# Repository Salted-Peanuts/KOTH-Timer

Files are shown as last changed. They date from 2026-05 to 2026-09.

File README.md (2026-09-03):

# KOTH-Timer

A DIY Arduino Nano ESP32 King of the Hill timer for Nerf, foam flinging, skirmish games, and objective-based events.

KOTH-Timer is an open-source physical game timer with arcade buttons, TM1637 displays, battery monitoring, and a local phone-friendly referee/admin web interface. It is designed for two-team King of the Hill games where players physically hold a button to capture the objective.

This project is based on a working timer that has been tested successfully at local Nerf events. A few people in the hobby scene asked how to build their own, so this repo exists to make that possible.

The goal is to keep it practical, buildable, and easy to modify.

## Current Recommended Versions

The current recommended firmware release is:

```text
v0.3.1
```

v0.3.1 is the recommended firmware for new builds.

It keeps the tested v0.3 phone/referee UI and adds small UI input fixes so team colours and match duration can be edited more reliably from the web interface.

Recommended PCB revision:

```text
v0.2
```

PCB v0.2 has been manufactured, assembled, and tested with no known faults. It is the recommended PCB revision for new builds.

The tested KOTH Timer PCB v0.2 project is available on PCBWay for convenience if you choose to use them:

[Order / view the KOTH Timer PCB v0.2 project on PCBWay](https://www.pcbway.com/project/shareproject/King_Of_The_Hill_ESP32_based_timer_1aeedfa7.html)

Older versions remain available for reference but are not recommended for new builds:

| Version | Status |
| --- | --- |
| Firmware v0.3 | Event-tested release, replaced by v0.3.1 bug-fix update |
| PCB v0.1 | Manufactured, functional through the web UI, but has known display issues |

## What It Does

KOTH-Timer is a physical objective timer for two-team King of the Hill style games.

Players press their team’s button to capture the objective. The timer tracks control time and shows the game state through:

* Large physical displays
* Button LED feedback
* A local referee/admin web interface

The timer runs locally from the ESP32, so it does not need internet access during gameplay.

## Prototype Photos

### Finished Prototype

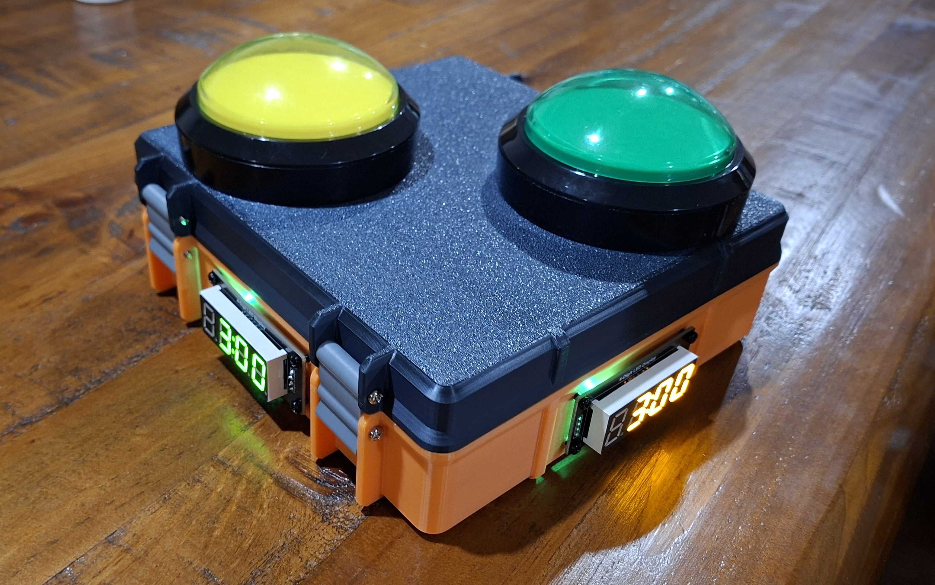
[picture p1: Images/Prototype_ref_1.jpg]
KOTH-Timer Timer finished prototype


### Inside Wiring

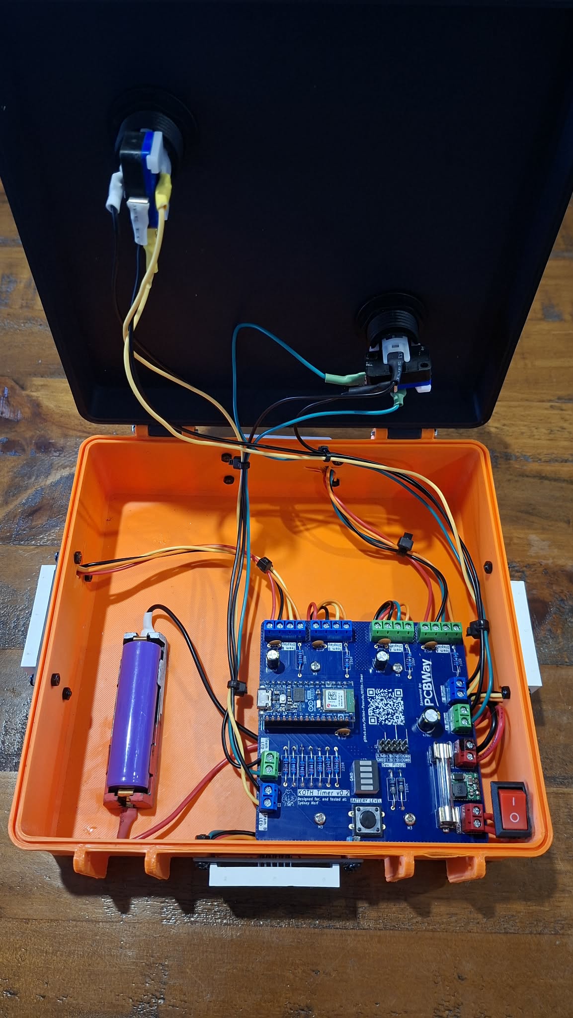
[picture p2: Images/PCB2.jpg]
KOTH-Timer Timer internal wiring


### Custom PCB

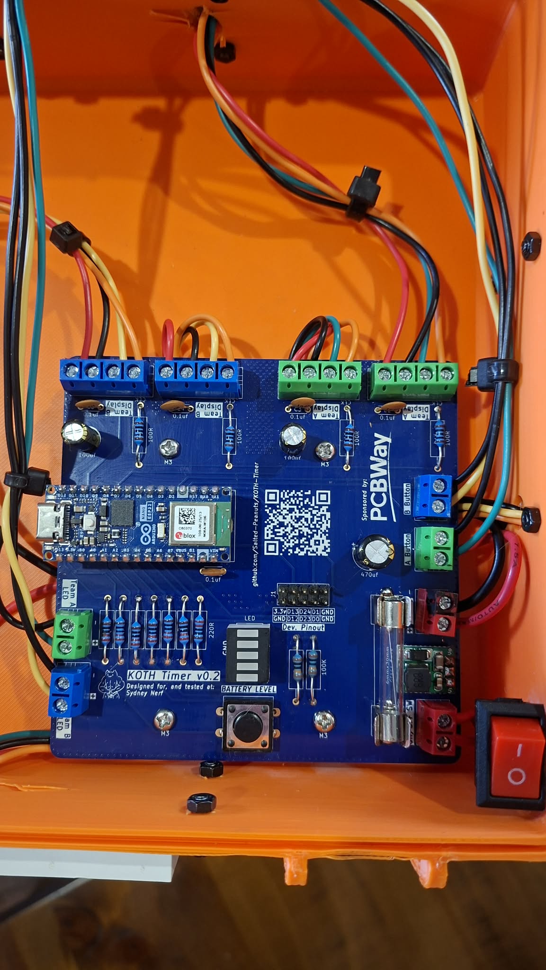
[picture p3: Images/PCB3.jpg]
KOTH-Timer Timer custom PCB


## Features

* Two-team King of the Hill timer
* Physical arcade button controls
* LED button feedback
* Four TM1637 4-digit display modules
* Local ESP32-hosted web interface
* Phone-friendly referee/admin controls
* Configurable match duration
* Configurable team colours
* Battery voltage display
* Pause and resume controls
* Reset lockout to prevent accidental resets
* Game-over winner display
* Live referee time adjustment during gameplay
* Open Wi-Fi network by default for quick event setup
* Optional Wi-Fi password support
* No internet required during gameplay

## Referee/Admin Connection

The timer creates its own local Wi-Fi network.

```text
SSID: KOTH-Timer
Password: none / open network
```

After connecting, open:

```text
http://10.10.10.1
```

Connection test page:

```text
http://10.10.10.1/ping
```

Some phones may warn that the network has no internet. This is normal. Choose the option to stay connected or use the network anyway.

## Optional Wi-Fi Password

The Wi-Fi network is open by default so referees can connect quickly during events.

If you want to add a password, edit the firmware near the top of the code.

Find:

```cpp
static const char* AP_PASS = "";
```

Change it to a password with at least 8 characters:

```cpp
static const char* AP_PASS = "kothtimer";
```

Then upload the firmware again.

## Who This Is For

This project is for hobbyists who want to build their own objective timer for games such as:

* Nerf events
* Foam flinging games
* Gel blaster games where legal
* Airsoft-style objective games where legal
* Backyard or club-based capture games
* Custom scenario games

You do not need to be an expert programmer, but you should be comfortable with basic wiring, soldering, and flashing an ESP32.

## Basic Hardware Needed

The current build uses:

* Arduino Nano ESP32
* 18650 Li-ion cell
* 18650 battery holder
* 5 V boost converter
* Fuse
* Rocker power switch
* 2 large arcade buttons with LEDs
* 4 TM1637 4-digit display modules
* 5-segment battery indicator
* Battery display button
* Resistors
* Wire
* Enclosure
* USB cable for flashing
* Basic soldering tools

See the `docs` folder for the BOM, schematic, and full build guide.

## Build Guide

Start here:

[Build Guide](docs/build-guide.md)

The build guide covers:

* Parts required
* Tools required
* Power wiring
* Arduino Nano ESP32 pinout
* Button wiring
* Display wiring
* Battery indicator wiring
* Firmware upload
* Wi-Fi connection
* Event-day testing
* Troubleshooting

## Firmware

The firmware is written for the Arduino Nano ESP32 using the Arduino IDE.

Current recommended firmware:

```text
Firmware/KOTH_Timer_v0_3_1/KOTH_Timer_v0_3_1.ino
```

For Arduino IDE compatibility, the `.ino` file should be inside a folder with the same name as the sketch.

## Hardware Files

Hardware documentation is in the `docs` folder.

Current files include:

```text
docs/BOM.xlsx
docs/BOM.csv
docs/Wiring_schematic.pdf
docs/build-guide.md
```
## PCB Hardware Status

The KOTH Timer now has a tested PCB revision.

| PCB revision | Status | Recommendation |
|---|---|---|
| `v0.1` | Manufactured and functionally usable through the web UI, but has known TM1637 display reliability issues | Reference only / not recommended for new builds |
| `v0.2` | Manufactured, assembled, and tested with no known faults | Recommended PCB revision |

### PCB v0.1

PCB v0.1 was the first manufactured PCB revision.

It is functional through the web UI, but some TM1637 displays may show interference, flicker, incorrect segments, or unstable output.

The v0.1 files are kept in the repo for reference, troubleshooting, and comparison, but new builders should use PCB v0.2 instead.

### PCB v0.2

PCB v0.2 is the current recommended PCB revision.

It was redesigned based on lessons from v0.1, with improvements around display reliability, local display decoupling, and cleaner TM1637 signal routing.

PCB v0.2 has been manufactured, assembled, and tested with no known faults.

## Supported By PCBWay

PCB manufacturing for newer KOTH Timer PCB revisions has been supported by **PCBWay**.

PCBWay helped support this open-source hardware project by providing PCB manufacturing support while allowing the firmware, design files, known issues, and documentation to remain open source.

Their support made it easier to test real PCB revisions, improve the board design, and share the results back with other builders.

You can check out PCBWay’s PCB manufacturing and assembly services here:

[PCBWay](https://pcbway.com/g/EGJ27l)

The tested KOTH Timer PCB v0.2 project is available on PCBWay here:

[Order / view the KOTH Timer PCB v0.2 project on PCBWay](https://www.pcbway.com/project/shareproject/King_Of_The_Hill_ESP32_based_timer_1aeedfa7.html)

Thanks to PCBWay for supporting open-source hardware creators and helping this project move from a hand-wired prototype to a tested PCB-based build.

Note: PCBWay supported manufacturing for this project, but the design notes, testing results, known issues, and recommendations in this repository are written independently.

## Future Development

Planned future work may include:

* Improving hardware documentation
* Adding more photos and wiring diagrams
* Adding extra game modes beyond King of the Hill
* Improving the referee/admin interface based on event feedback
* Exploring a Bluetooth or app-based version if there is enough interest

The v0.3.1 firmware is the current recommended release. It is based on the event-tested v0.3 firmware and includes additional web-interface input fixes.

PCB v0.2 has been manufactured, assembled, and tested with no known faults and is the current recommended PCB revision.

## Project Status

This is a hobby project, not a commercial product.

The current firmware has been tested at an event, but builders should still test their own wiring and setup before using the timer in a game.

If you build one, feel free to modify it for your own event rules, enclosure, buttons, battery setup, or game style.

## Related Uses

This project may be useful for:

- Nerf King of the Hill games
- Foam flinging objective games
- DIY skirmish game timers
- Arduino ESP32 game props
- Capture point timers
- Referee-controlled event timers
- Local Wi-Fi game control panels

## Licence

This project is released under the MIT Licence.

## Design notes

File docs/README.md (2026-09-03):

## KOTH Timer Documentation

This folder contains the main hardware and build documentation for the KOTH Timer.

The current recommended firmware release is **v0.3.1**.

v0.3.1 has been tested and is now the recommended version for new builds.

## PCBWay Project Link

This tested PCB revision is available as a PCBWay shared project:

[Order / view the KOTH Timer PCB v0.2 project on PCBWay](https://www.pcbway.com/project/shareproject/King_Of_The_Hill_ESP32_based_timer_1aeedfa7.html)

This link is useful for builders who want to order the tested PCB without manually uploading the Gerber files.

## Build Guide

Start here:

```text
docs/build-guide.md
```

The build guide covers:

* Required parts
* Required tools
* Wiring overview
* Arduino Nano ESP32 pinout
* Power wiring
* Button wiring
* Display wiring
* Battery indicator wiring
* Firmware upload
* Wi-Fi/admin page connection
* Event testing
* Troubleshooting

## BOM

The bill of materials is available in two formats:

```text
docs/BOM.xlsx
docs/BOM.csv
```

Use the Excel file if you want the formatted version.

Use the CSV file if you want something easier to view directly on GitHub.

## Schematic

The current wiring schematic is available as a PDF:

```text
docs/Wiring_schematic.pdf
```

Use the schematic together with the build guide and firmware pinout before soldering.

## Firmware Version

The current recommended firmware is:

```text
v0.3.1
```

The older v0.2 and v0.3 firmware releases remain available for reference, but new builders should use v0.3.1:

```text
Firmware/KOTH_Timer_v0_3_1/KOTH_Timer_v0_3_1.ino
```

## Wi-Fi/Admin Interface

By default, the timer creates an open Wi-Fi network:

```text
SSID: KOTH-Timer
Password: none / open network
```

After connecting, open:

```text
http://10.10.10.1
```

Connection test page:

```text
http://10.10.10.1/ping
```

The timer does not provide internet access. This is normal.

Some phones may warn that the Wi-Fi network has no internet. Choose the option to stay connected or use the network anyway.

## Optional Wi-Fi Password

The Wi-Fi network is open by default for quick event setup.

To add a password, edit the firmware.

Find:

```cpp
static const char* AP_PASS = "";
```

Change it to a password with at least 8 characters:

```cpp
static const char* AP_PASS = "kothtimer";
```

Then upload the firmware again.

## Notes

This hardware is based on the tested prototype build.

Check all wiring carefully before powering the device.

Some parts may need different resistor values or pin assignments depending on the exact components used.

Use a multimeter before connecting the Arduino and displays to the battery power system.

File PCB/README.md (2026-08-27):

# KOTH Timer PCB Files

This folder contains PCB design files for the KOTH Timer.

Check the status of each PCB revision before ordering or manufacturing boards.

## PCB Revision Status

| Revision | Status | Use |
|---|---|---|
| `v0.1` | Manufactured, functionally usable through the web UI, known display issues | Reference only / not recommended for new builds |
| `v0.2` | Manufactured, assembled, and tested with no known faults | Recommended PCB revision |

## PCB v0.1

PCB v0.1 was the first manufactured PCB revision.

It is functionally usable through the timer’s web UI, but it has known TM1637 display reliability issues.

Known issue:

- Some TM1637 displays may show interference, flicker, incorrect segments, or unstable output.

Possible contributing factors include:

- Shared TM1637 clock routing
- Not enough local decoupling near the display headers
- Display power noise
- Signal integrity issues on CLK/DIO traces
- Long display wiring or cable effects

This revision is kept for reference and comparison, but it is not recommended for new builders.

## PCB v0.2

PCB v0.2 is the current recommended PCB revision.

It has been manufactured, assembled, and tested with no known faults.

This revision improves on v0.1, especially around:

- TM1637 display reliability
- Local display power decoupling
- Cleaner display signal routing
- Improved PCB layout
- Reduced display interference issues

## Recommendation

For new builders:

- Use the current recommended firmware.
- Use PCB v0.2 if building from a PCB.
- Use PCB v0.1 only for reference or debugging.
- Check the main build guide before ordering parts or assembling the board.

## Supported By PCBWay

PCB manufacturing for newer KOTH Timer PCB revisions has been supported by PCBWay.

Their support helped make it possible to test real PCB revisions and keep the project open source.

The tested KOTH Timer PCB v0.2 project is available on PCBWay here:

[Order / view the KOTH Timer PCB v0.2 project on PCBWay](https://www.pcbway.com/project/shareproject/King_Of_The_Hill_ESP32_based_timer_1aeedfa7.html)

Project files, known issues, testing notes, and recommendations remain documented openly so other builders can inspect, build, and improve the design.

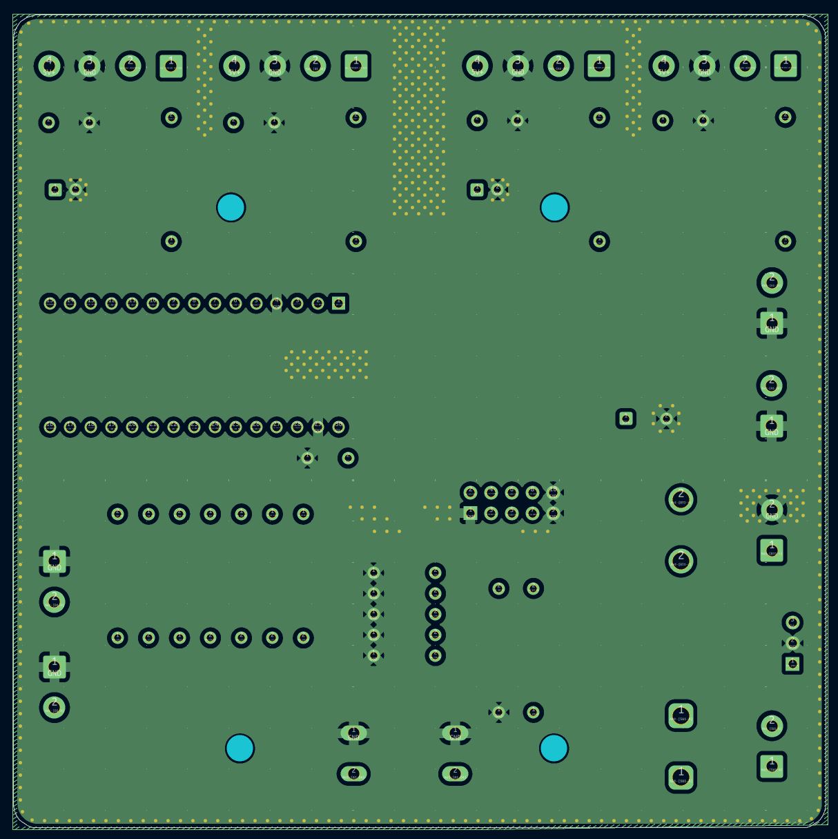
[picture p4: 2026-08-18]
Images/v0.2_Layer2.JPG

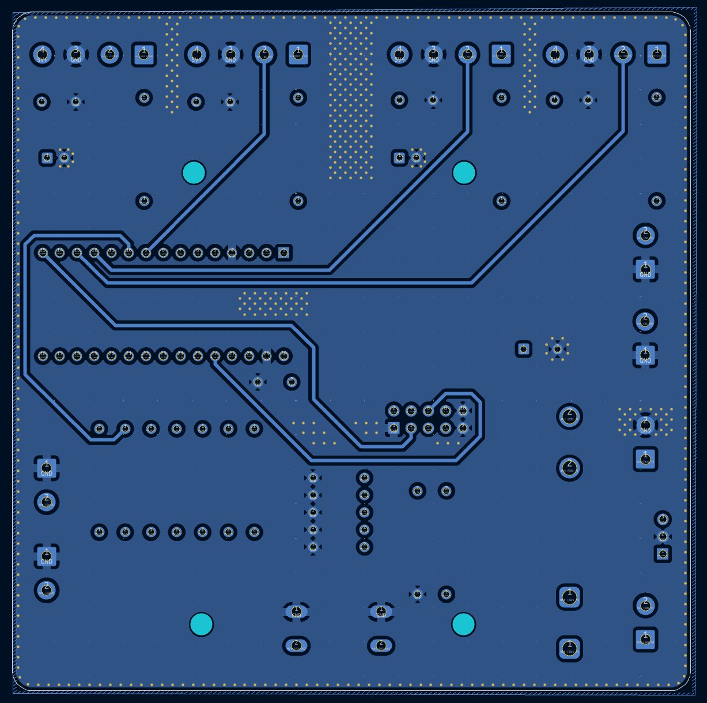
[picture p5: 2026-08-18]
Images/v0.2_Layer4.JPG

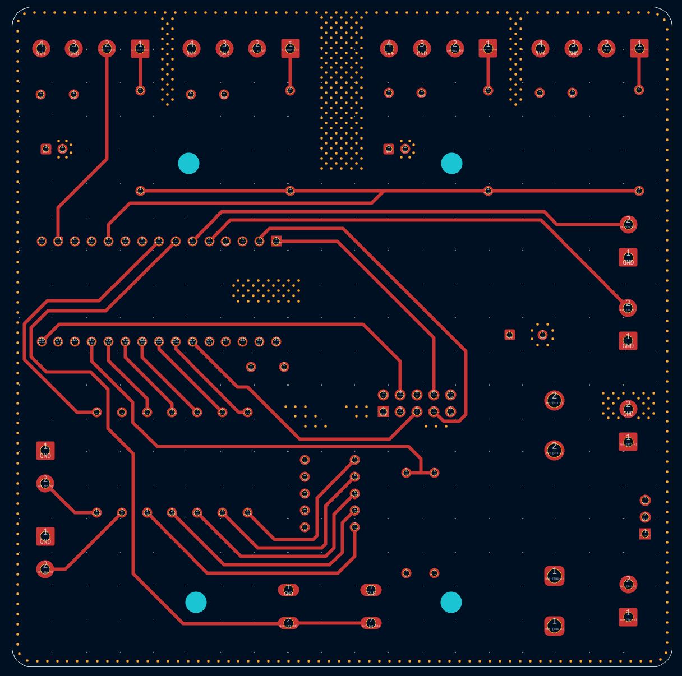
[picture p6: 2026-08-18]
Images/v0.2_Layer1.JPG

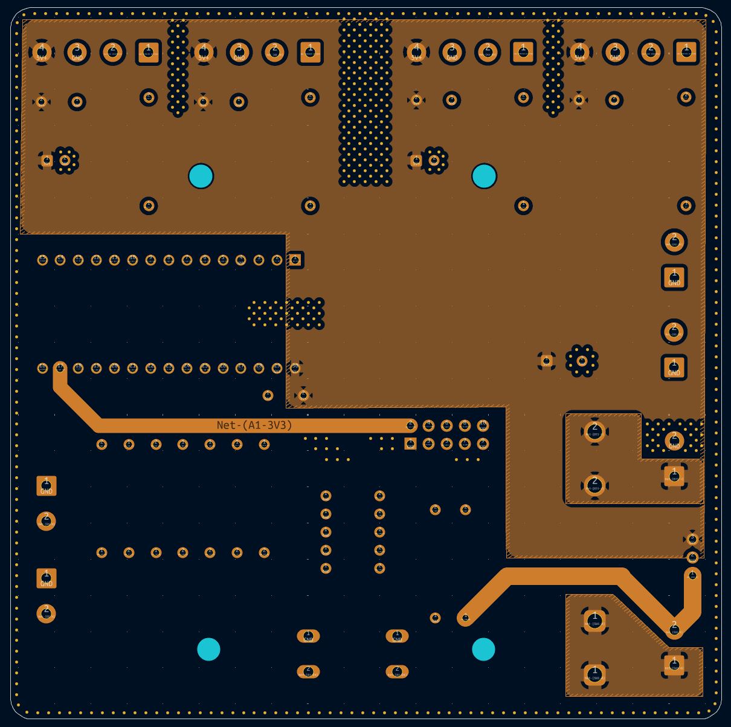
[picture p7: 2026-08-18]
Images/v0.2_Layer3.JPG

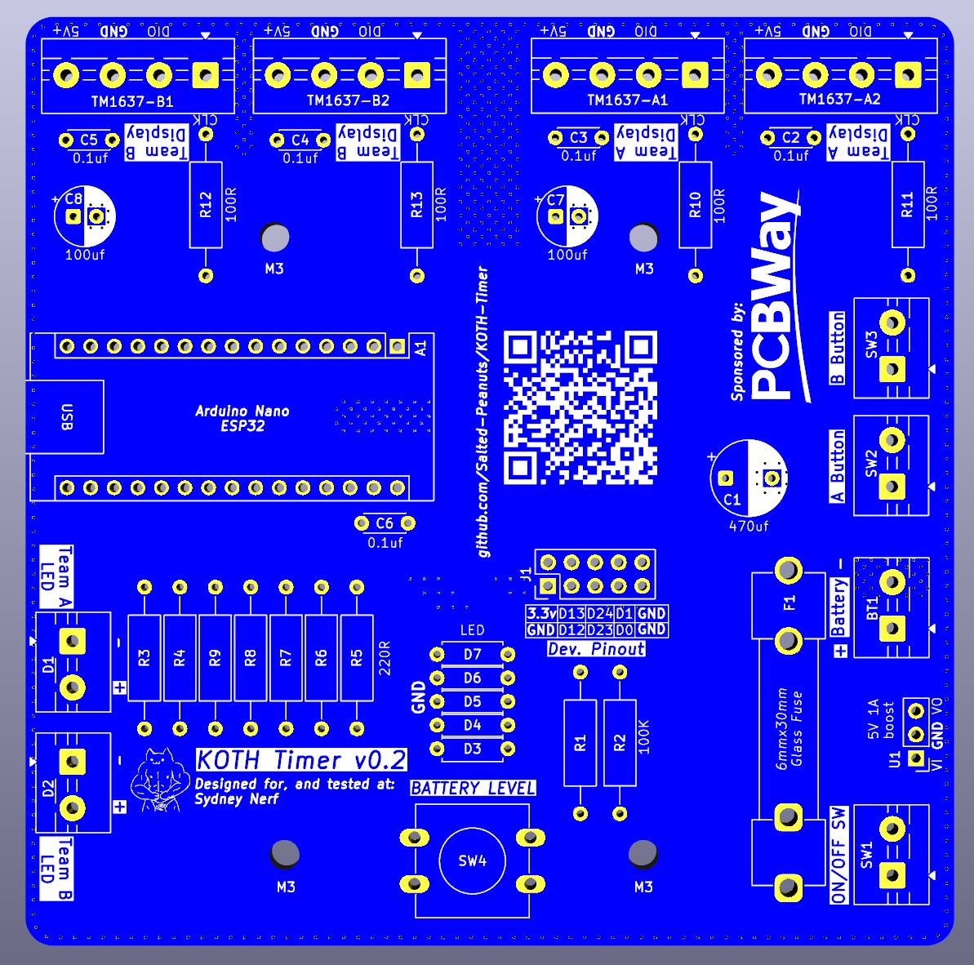
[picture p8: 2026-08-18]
Images/v0.2_FRONT.JPG

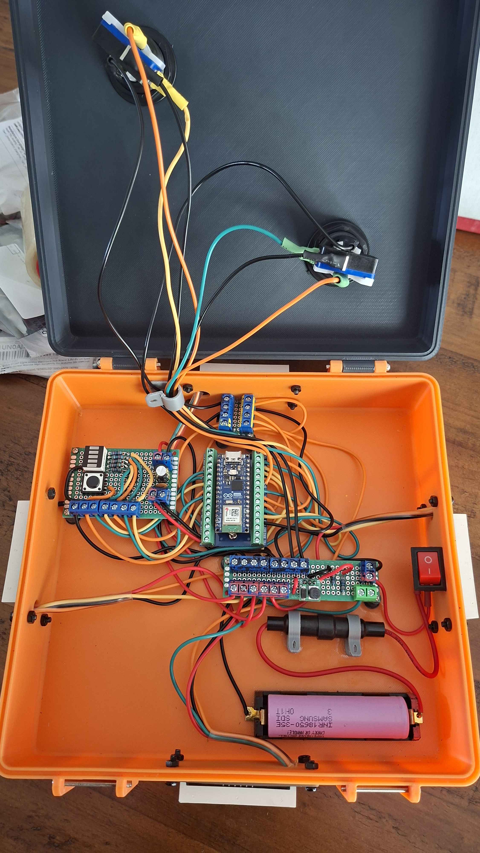
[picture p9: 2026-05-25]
Images/Prototype_ref_3.jpg

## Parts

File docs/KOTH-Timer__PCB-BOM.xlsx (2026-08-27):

 |  |  | KOTH-Timer BOM
Item # | *Designator | Qty | Manufacturer | Description / Value | Package/Footprint | Type | Your Instructions / Notes
1 | A1 | 1 | Arduino | Arduino NANO-ESP32 | Arduino Nano ESP32 module / header footprint | THT | Main controller module
2 | U1 | 1 |  | 5V step-up / boost converter module | 2.54mm pitch | THT | 1 Amp
3 | BT1, D1, D2, SW1, SW2, SW3 | 6 |  | Terminal Block - 2 pin (5mm pitch) | 2-pin 5.00mm pitch | THT
4 | TM1637-A1, TM1637-A2, TM1637-B1, TM1637-B2 | 4 |  | Terminal Block - 4 pin (5mm pitch) | 4-pin 5.00mm pitch | THT
5 | F1 | 2 |  | Fuse Clips for 6mm x 30mm Glass | 6x30mm fuse clip | THT | Pair of clips holds one fuse
6 | SW4 | 1 |  | 12mm push button switch | 12mm push button | THT
7 | D3-D7 | 1 |  | 5 Segment Bar Graph LED Display Module | 5-segment LED module | THT
8 | J1 | 1 |  | 10 pin double row (2x5) Pin header - 2.54mm pitch | 2x5 2.54mm pitch | THT
9 | R1, R2 | 2 |  | 100K resistor | Axial resistor | THT
10 | R3-R9 | 7 |  | 220R resistor | Axial resistor | THT
11 | R10-R13 | 4 |  | 100R resistor | Axial resistor | THT
12 | C1 | 1 |  | 470uF electrolytic capacitor | Radial electrolytic | THT | Observe polarity
13 | C7, C8 | 2 |  | 100uF electrolytic capacitor | Radial electrolytic | THT | Observe polarity
14 | C2-C6 | 5 |  | 100nF ceramic capacitor | Ceramic capacitor | THT
15 |  | 1 |  | 6mm x 30mm 1A glass fuse | 6x30mm glass fuse | DNS | Replaceable fuse
16 |  | 1 |  | 18650 Li-ion cell | Off-board | DNS | Install separately; do not assemble to PCB
17 |  | 1 |  | 18650 battery holder | Off-board / wired | DNS | Install in enclosure
18 |  | 1 |  | Rocker switch (ON/OFF) | Panel mount / wired | DNS | Install in enclosure
19 |  | 4 |  | TM1637 4-Digit LED Display | 4-pin external module | DNS | External display modules
20 |  | 2 |  | Arcade LED Button | Panel mount / wired | DNS | External illuminated arcade buttons
21 |  | 1 |  | Wire as needed (22 AWG) | Off-board | DNS | Assembly wiring as required
22 |  | 1 |  | Enclosure of your choice | Off-board | DNS | Mechanical item

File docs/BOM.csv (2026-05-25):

Reference | Qty | Value | Description: | Product links:
A1 | 1x | Arduino_Nano_ESP32 | Arduino branded ESP32 Board (Code will not work with generic ESP32 family devices) | https://core-electronics.com.au/arduino-nano-esp32.html
BT1 | 1x | 18650_Cell | 18650 battery cell | https://www.jaycar.com.au/18650-samsung-3500mah-3-7v-flat-top-li-ion-rechargeable-battery/p/SB2630
C1 | 1x | 470uf_E_Cap | 470uf electrolytic capacitor | https://www.jaycar.com.au/470uf-16vdc-low-esr-electrolytic-capacitor/p/RE6314
C2 | 1x | 0.1uf_C_Cap | 0.1uf (100nf) ceramic capacitor | https://www.jaycar.com.au/100nf-50vdc-ceramic-capacitors-pack-of-2/p/RC5360
D3,D4,D5,D6,D7 | 1x | LED_RED, LED_YELLOW, LED_GREEN | 5 segement LED bar graph (any colours you prefer. I used one with 3x green bars, 1x yellow bar, 1x red bar) | https://www.aliexpress.com/item/1005010479786364.html
F1 | 1x | 2.5-3A_Fuse | 2.5a-3a Glass tube fuse with some sort of holder (Use wire thicker than your fuse for runs) | https://www.aliexpress.com/item/1005007846817140.html
R1,R2 | 2x | 100K | 100k resistor | https://www.jaycar.com.au/100k-ohm-0-5-watt-metal-film-resistors-pack-of-8/p/RR0620
R3,R4,R5,R6,R7,R8,R9 | 7x | 220R | 220R resistor | https://www.jaycar.com.au/220k-ohm-0-5-watt-metal-film-resistors-pack-of-8/p/RR0628
SW1 | 1x | Rocker_Switch | on/off rocker style (or your prefence) for device power on and off | https://www.aliexpress.com/item/4001108045600.html
SW2,SW3,D1,D2 | 2x | Push_Switch (Team_A), Push_Switch (Team_B) | 100mm Arcade style push buttons with LEDs | https://www.aliexpress.com/item/33029152680.html
SW4 | 1x | SW_Push | PCB button switch: For turning 5 segment display on to see battery level | https://www.jaycar.com.au/spst-pcb-mount-tactile-switch-round/p/SP0609
TM1637 | 4x | 4_Digit_DIsplay (Team_A), 4_Digit_DIsplay (Team_B) | TM1637 4-digit 7-segment display (2x of two diffent colours for each teams time keeping) | https://www.aliexpress.com/item/1005001582129952.html
U1 | 1x | 5v_Step_Up | 0.9-5V to 5V DC-DC Step-Up Power Module | https://www.amazon.com.au/dp/B0CWXM62Y5?ref=ppx_yo2ov_dt_b_fed_asin_title
 | 1x | 18650 battery cell holder | you can also find them local at jaycar | https://www.amazon.com.au/dp/B0CQ73GFVY?ref=ppx_yo2ov_dt_b_fed_asin_title&th=1
 |  | PCBs | Prototyping PCBs (for soldering eveything to) | https://www.aliexpress.com/item/1005007549507093.html
 |  | Insulated wire (I used 22 AWG) | Insulated wire (I used 22 AWG)
 |  | Heat shrink
 |  | Arduino Nano Breakout board
 |  | Terminal blocks as required

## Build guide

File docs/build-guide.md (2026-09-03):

# KOTH Timer Build Guide

This guide explains how to build the current recommended version of the KOTH Timer.

KOTH Timer is a DIY King of the Hill timer for Nerf, foam flinging, and other objective-based hobby games. It uses an Arduino Nano ESP32, two large team buttons, four TM1637 display modules, LED feedback, a battery display, and a local Wi-Fi web interface for controlling the game.

This guide is based on **KOTH Timer v0.3.1**, which keeps the event-tested v0.3 gameplay and referee UI while adding fixes for the web-interface setup controls.

> **Important:** This is still a hobby project. Check the schematic, BOM, firmware, and photos before soldering. Builders should test their own wiring carefully before using the timer at an event.

## Build Guide Status:

This Build guide is in place for use ONLY if you plan to build the timer using prototype boards instead of the PCB. There is currently no updated build guide for the manufactured PCB. However, I designed the PCB to be as self explanatory (with a bit of context) as possible. It relies on headers/terminals for most major components so it is PNP for the most part. 

## PCBWay Project Link

This tested PCB revision is also available as a PCBWay shared project:

[Order / view the KOTH Timer PCB v0.2 project on PCBWay](https://www.pcbway.com/project/shareproject/King_Of_The_Hill_ESP32_based_timer_1aeedfa7.html)

This link is useful for builders who want to order the tested PCB without manually uploading the Gerber files.

## What You Are Building

The timer has two teams.

Each team has:

* One large arcade button
* One LED output for button feedback
* Two 4-digit TM1637 display modules showing that team’s remaining time

The timer also has:

* An Arduino Nano ESP32 controller
* A single 18650 battery power system
* A 5 V boost converter
* A rocker power switch
* A fuse
* A 5-segment battery indicator
* A small battery-check button
* A local Wi-Fi web interface hosted by the ESP32

The game logic is simple:

* If Team A holds their button, Team A’s timer counts down.
* If Team B holds their button, Team B’s timer counts down.
* If both buttons are held, the point is contested and neither timer counts down.
* If no button is held, neither timer counts down.
* The match ends when one team’s timer reaches zero.

## Current Status

The current recommended firmware release is **v0.3.1**.

v0.3.1 keeps the tested v0.3 phone/referee UI and adds small UI input fixes for the setup controls.

The current recommended PCB revision is **PCB v0.2**.

PCB v0.2 has been manufactured, assembled, and tested with no known faults.

New builders should use:

```text
Firmware/KOTH_Timer_v0_3_1/KOTH_Timer_v0_3_1.ino
PCB/v0.2-tested/
```

Main v0.3.1 improvements include:

* Phone-friendly referee/admin web interface
* More reliable phone connection using `http://10.10.10.1`
* Open Wi-Fi network by default for quick event setup
* Optional Wi-Fi password support if the builder wants it
* Live time adjustment during gameplay
* Ref/admin can add or remove time from either team without resetting the match
* Larger touch-friendly controls
* Cleaner match status display
* `/ping` test page for connection troubleshooting
* `/state` fallback endpoint for UI updates

The older v0.2 firmware is still available for reference, but new builders should use v0.3.1.

## Parts Required

The BOM includes:

| Qty | Part | Notes |
| ---: | --- | --- |
| 1 | Arduino Nano ESP32 | Arduino-branded Nano ESP32 |
| 1 | 18650 Li-ion cell | Single-cell battery |
| 1 | 18650 battery holder | Holds the battery |
| 1 | 5 V step-up converter | Boosts the 18650 voltage to 5 V |
| 1 | 1 A fuse | Use with a suitable fuse holder |
| 1 | Rocker switch | Main power switch |
| 2 | Large arcade buttons with LEDs | One for each team |
| 4 | TM1637 4-digit display modules | Two displays per team |
| 1 | 5-segment LED bar graph | Battery level display |
| 1 | Small push button | Battery display button |
| 2 | 100 kΩ resistors | Battery voltage divider |
| 7 | 220 Ω resistors | LED current limiting |
| 1 | 470 µF electrolytic capacitor  | Power smoothing |
| 1 | 100 nF ceramic capacitor | Power smoothing/decoupling |
| As needed | Prototyping PCB | For soldering |
| As needed | Wire | 22 AWG was used in the original build |
| As needed | Heat shrink | For insulation |
| As needed | Terminal blocks | Optional, but useful |
| 1 | Enclosure | 3D printed or custom housing |

## Tools Required

You will need:

* Soldering iron
* Solder
* Wire cutters
* Wire strippers
* Heat shrink or electrical tape
* Small screwdrivers
* Multimeter
* USB cable for the Arduino Nano ESP32
* Computer with Arduino IDE installed

A multimeter is strongly recommended. Do not skip voltage checks.

## Power Wiring Overview

The timer is powered from a single 18650 cell.

Basic power path:

```text
18650 battery
  -> fuse
  -> rocker power switch
  -> 5 V boost converter
  -> Arduino Nano ESP32 VIN / 5 V rail
```

All grounds must be connected together.

```text
Battery GND
Boost converter GND
Arduino GND
Display GND
Button LED GND
Battery indicator GND
```

> **Important:** Do not connect the 18650 battery directly to the Arduino 5 V or VIN pin without the boost converter/power circuit.

> **Li-ion safety:** Use care when working with 18650 cells. Avoid shorts, use a fuse, and do not use damaged cells.

## Arduino Nano ESP32 Pinout

The v0.3.1 firmware uses the following pin assignments.

### Team Buttons

The team buttons are wired to ground and use the ESP32 internal pull-up resistors.

| Function | Arduino Pin | Wiring |
| --- | --- | --- |
| Team A button | D2 | Button between D2 and GND |
| Team B button | D3 | Button between D3 and GND |
| Battery display button | D4 | Button between D4 and GND |

Button logic:

```text
Pressed = LOW
Released = HIGH
```

### Arcade Button LEDs

The arcade button LEDs are driven from GPIO pins.

| Function | Arduino Pin | Wiring |
| --- | --- | --- |
| Team A button LED | D5 | D5 -> resistor -> LED -> GND |
| Team B button LED | D7 | D7 -> resistor -> LED -> GND |

LED logic:

```text
HIGH = LED on
LOW = LED off
```

Use suitable resistors for your LEDs. The BOM lists 220 Ω resistors.

### TM1637 Displays

The timer uses four TM1637 4-digit displays.

All four displays share the same clock pin, but each display has its own data pin.

| Display | Clock Pin | Data Pin |
| --- | --- | --- |
| Team A display 1 | D8 | D9 |
| Team A display 2 | D8 | D10 |
| Team B display 1 | D8 | D11 |
| Team B display 2 | D8 | D6 |

Typical TM1637 wiring:

```text
TM1637 VCC -> 5 V / VIN rail
TM1637 GND -> GND
TM1637 CLK -> D8
TM1637 DIO -> display data pin
```

The two displays for the same team show the same time. This lets the timer be visible from more than one angle.

### Battery Voltage Reading

The battery voltage is measured through a resistor divider.

| Function | Arduino Pin |
| --- | --- |
| Battery voltage divider midpoint | A0 |

The timer uses:

```text
R1 = 100 kΩ
R2 = 100 kΩ
```

Basic divider:

```text
Battery +
  -> R1
  -> A0
  -> R2
  -> GND
```

> **Important:** Do not connect the battery directly to A0. The battery voltage must go through the resistor divider.

The firmware includes battery calibration values. If the displayed battery voltage is wrong, measure the battery with a multimeter and adjust the calibration values in the firmware.

### 5-Segment Battery Indicator

The battery indicator uses five GPIO outputs.

| Segment | Arduino Pin |
| --- | --- |
| Red segment | A1 |
| Yellow segment  | A2 |
| Green segment 1 | A3 |
| Green segment 2 | A4 |
| Green segment 3 | A5 |

The firmware assumes:

```text
GPIO HIGH = segment on
GPIO LOW = segment off
```

Each LED segment should have current limiting.

The battery bar display turns on temporarily when the battery display button is pressed.

## Wiring Checklist

Before soldering everything permanently, build and test in sections.

### 1. Power System

Check:

* Fuse is installed
* Rocker switch controls power
* Boost converter outputs 5 V
* Arduino powers up from the 5 V supply
* Ground is common everywhere

Use a multimeter before plugging in the Arduino.

### 2. Buttons

Wire:

```text
Team A button -> D2 and GND
Team B button -> D3 and GND
Battery button -> D4 and GND
```

No external pull-up resistor is needed for these buttons because the firmware uses `INPUT_PULLUP`.

### 3. Arcade Button LEDs

Wire:

```text
D5 -> resistor -> Team A LED -> GND
D7 -> resistor -> Team B LED -> GND
```

If your arcade buttons have built-in LEDs, check their voltage and polarity before wiring.

### 4. Displays

Wire all TM1637 modules to power and ground.

Then connect:

```text
All display CLK pins -> D8

Team A display 1 DIO -> D9
Team A display 2 DIO -> D10
Team B display 1 DIO -> D11
Team B display 2 DIO -> D6
```

If one display does not work, swap it with a known working one to check whether the issue is the display module or the wiring.

### 5. Battery Indicator

Wire the 5-segment bar graph using the schematic.

Firmware pin order:

```text
A1 = red
A2 = yellow
A3 = green 1
A4 = green 2
A5 = green 3
```

Pressing the battery display button should show the battery level for a few seconds.

## Firmware Upload

The firmware is written for the Arduino Nano ESP32 using the Arduino IDE.

### 1. Install Arduino IDE

Install Arduino IDE 2.x.

### 2. Install ESP32 Board Support

In Arduino IDE, install the board support needed for the Arduino Nano ESP32.

Select the Arduino Nano ESP32 board before compiling.

### 3. Install Required Libraries

The firmware uses:

* Wi-Fi support for the ESP32
* Web server support
* WebSockets support
* TM1637 display support
* Preferences storage
* DNS server support for connection handling

If the code fails to compile because a library is missing, install the missing library through:

```text
Arduino IDE -> Library Manager
```

Search for the missing library name shown in the compile error.

### 4. Open the Firmware

Open the `.ino` file from the `Firmware` folder.

For Arduino IDE compatibility, the sketch should be inside a folder with the same name as the `.ino` file.

Example:

```text
Firmware/
  KOTH_Timer_v0_3_1/
    KOTH_Timer_v0_3_1.ino
```

### 5. Upload

Connect the Arduino Nano ESP32 over USB.

Then click:

```text
Upload
```

After uploading, the ESP32 should start its local Wi-Fi access point.

## First Power-On Test

Before closing the enclosure, test everything on the bench.

### Check Displays

On boot, the TM1637 displays should show the starting game time.

If the displays are blank:

* Check 5 V and GND
* Check D8 clock wiring
* Check each display’s DIO pin
* Check display orientation
* Check the firmware uploaded correctly

### Check Wi-Fi

The ESP32 creates a local Wi-Fi network:

```text
SSID: KOTH-Timer
Password: none / open network
```

Connect to it with a phone or laptop.

There is no internet through this network. That is normal.

Open a browser and go to:

```text
http://10.10.10.1
```

The KOTH Timer web interface should load.

If the main page does not load, test the connection page:

```text
http://10.10.10.1/ping
```

If `/ping` loads but the main page does not, the Wi-Fi connection is working and the issue is likely with the web interface loading or browser caching.

Some phones may warn that the network has no internet. Choose the option to stay connected or use the network anyway.

### Optional: Adding a Wi-Fi Password

By default, the KOTH Timer Wi-Fi network is open so referees can connect quickly during events.

If you want to add a password, edit the firmware Wi-Fi settings near the top of the code.

Find:

```cpp
static const char* AP_PASS = "";
```

Change it to something with at least 8 characters:

```cpp
static const char* AP_PASS = "kothtimer";
```

Then upload the firmware again.

After that, users will need to connect with:

```text
SSID: KOTH-Timer
Password: kothtimer
```

The password must be at least 8 characters long. If the password is left blank, the timer will use an open network.

### Check Buttons

Start a test game from the web interface.

Then test:

* Hold Team A button: Team A timer should count down.
* Hold Team B button: Team B timer should count down.
* Hold both buttons: contested state, no timer should count down.
* Hold no buttons: idle state, no timer should count down.

### Check LED Feedback

During a running game:

* Team A capturing should light Team A LED.
* Team B capturing should light Team B LED.
* Contested should light both LEDs.
* Idle should turn both LEDs off.

### Check Battery Display

Press the battery display button.

The 5-segment bar graph should light briefly to show the approximate battery level.

If the displayed battery level is wrong, measure the battery voltage with a multimeter and calibrate the firmware.

## Web Interface Use

The web interface allows the referee/admin to:

* Start the game
* Pause the game
* Resume the game
* Reset the game
* Set match duration
* Set team colours
* Identify teams
* View battery voltage
* View current game state
* See the winner when the match ends
* Add or remove time from either team during gameplay

The reset button is only intended to work when the game is paused or when the match has finished.

The live time adjustment controls are intended for referee/admin corrections during a match. They can be used to fix timing issues without resetting the whole game.

## Game Rules

The current firmware uses hold-to-capture logic.

| Button State | Result |
| --- | --- |
| Team A held only | Team A timer counts down |
| Team B held only | Team B timer counts down |
| Both buttons held | Contested, no timer counts down |
| No buttons held | Idle, no timer counts down |
| A timer reaches zero | Match ends |

This makes the timer useful for King of the Hill games where teams must physically hold the objective.

## Mounting Everything

The original build uses a custom enclosure, but you can use any suitable housing.

When laying out the enclosure, consider:

* Buttons should be large and easy to hit during games.
* Displays should be visible from a distance.
* The power switch should be protected from accidental bumps.
* The USB port should still be accessible if possible.
* The battery should be secure and not able to rattle around.
* Wires should be strain-relieved.
* Solder joints should be insulated.
* The fuse should be accessible.

Do not leave bare battery connections exposed.

## Final Pre-Game Checklist

Before using the timer at an event:

* Battery fully charged
* Fuse installed
* Power switch working
* Displays visible
* Both team buttons working
* Both team LEDs working
* Battery indicator working
* Phone/laptop can connect to `KOTH-Timer`
* Web interface loads at `http://10.10.10.1`
* `/ping` test page works
* Start/pause/resume/reset tested
* Live time adjustment tested
* Match duration set correctly
* Enclosure closed and secure

## Troubleshooting

### The ESP32 Does Not Turn On

Check:

* Battery voltage
* Fuse
* Rocker switch
* Boost converter output
* 5 V connection to the Arduino
* Ground wiring

### The Wi-Fi Network Does Not Appear

Check:

* Firmware uploaded correctly
* Correct board selected in Arduino IDE
* Arduino is actually powered
* Try pressing reset on the board
* Try powering from USB first

### The Web Interface Does Not Load

Check:

* Your phone/laptop is connected to `KOTH-Timer`
* Your phone has chosen to stay connected to the no-internet Wi-Fi network
* Mobile data is not interfering
* Disable any VPNs
* Try opening `http://10.10.10.1`
* Try opening `http://10.10.10.1/ping`
* Try another browser
* Restart the timer

### A Team Button Does Not Work

Check:

* One side of the button goes to the correct GPIO
* The other side goes to GND
* You used D2 for Team A and D3 for Team B
* The button is normally open
* The wire has not broken off the terminal

### A Button Works Backwards

The firmware expects the buttons to connect the pin to GND when pressed.

Use the normally open contacts on the arcade button.

### A Display Is Blank

Check:

* VCC
* GND
* CLK wire to D8
* DIO wire to the correct pin
* Display module orientation
* Solder joints
* Try swapping with a known working display

### Both Displays for One Team Are Wrong

Check the data pins for that team:

```text
Team A display 1 -> D9
Team A display 2 -> D10

Team B display 1 -> D11
Team B display 2 -> D6
```

### Battery Reading Is Wrong

Check:

* The resistor divider is wired correctly
* R1 and R2 are both 100 kΩ
* The divider midpoint goes to A0
* Battery ground and Arduino ground are common
* The firmware calibration value matches your real measured battery voltage

Use a multimeter to compare the real battery voltage against the web interface reading.

### Battery Bar Graph Does Not Light

Check:

* Battery display button wiring
* Bar graph common pin wiring
* Segment polarity
* Current-limiting resistors
* Pins A1 to A5
* Ground connection

### Timer Does Not Count Down

Check:

* Game has been started from the web interface
* Game is not paused
* Only one team button is being held
* The button wiring is correct
* The web interface state is not showing contested or idle

### Live Time Adjustment Does Not Work

Check:

* You are using the v0.3.1 firmware
* The web interface is loaded properly
* The phone is still connected to the timer Wi-Fi
* Try refreshing the page
* Try opening `http://10.10.10.1/ping`

The live time adjustment controls are included in the v0.3.1 web interface.

## Notes for Builders

This is not a polished commercial product. It is a hobby project based on a working event-tested build.

Expect to do some testing and troubleshooting.

You can modify:

* Team colours
* Enclosure design
* Button style
* Display colours
* Battery setup
* Match rules
* Firmware behaviour

If you improve the design, consider sharing your changes back with the project.

## Future Development Plans

v0.3.1 is the current recommended firmware release.

Planned future work may include:

* Improving the PCB assembly documentation
* Making the hardware documentation clearer for new builders
* Adding more photos and diagrams to the build guide
* Adding extra game modes beyond King of the Hill
* Improving the referee/admin interface further based on event feedback
* Exploring a Bluetooth or app-based version if there is enough interest

PCB v0.2 has been manufactured, assembled, and tested with no known faults. It is the recommended PCB revision for new PCB-based builds.

## Safety Notes

* Be careful with Li-ion batteries.
* Use a fuse.
* Do not short the battery.
* Insulate exposed solder joints.
* Do not leave loose wires inside the enclosure.
* Check polarity before powering the device.
* Do not use damaged cells.
* Do not charge the battery unattended unless your charging setup is designed for safe unattended use.

## Version

Guide written for:

```text
KOTH Timer v0.3.1
```

v0.3.1 is the current recommended firmware release.

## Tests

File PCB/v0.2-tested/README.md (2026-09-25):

# KOTH Timer PCB v0.2 - Tested (Working)

This folder contains the second PCB revision for the KOTH Timer.

## Status

**Manufactured, assembled, and tested with no known faults.**

PCB v0.2 is the current recommended PCB revision for new builds.

## What Changed From v0.1

PCB v0.2 was redesigned after testing PCB v0.1.

The v0.1 board was functionally usable through the web UI, but some TM1637 displays showed reliability issues.

PCB v0.2 improves the design with better attention to:

- Display power decoupling
- TM1637 CLK/DIO routing
- Display signal reliability
- Ground and power layout
- Dev Pinout for easier future module development 
- PCB revision clarity

## Recommendation

Use this revision for new PCB-based KOTH Timer builds.

## Before Ordering

Even though PCB v0.2 has been tested successfully, builders should still check:

- Arduino Nano ESP32 pin assignments
- TM1637 display header pinout
- Battery/Capacitor polarity
- Fuse and switch wiring
- Display module pin order
- BOM compatibility
- Firmware version

## PCBWay Project Link

This tested PCB revision is also available as a PCBWay shared project:

[Order / view the KOTH Timer PCB v0.2 project on PCBWay](https://www.pcbway.com/project/shareproject/King_Of_The_Hill_ESP32_based_timer_1aeedfa7.html)

This link is useful for builders who want to order the tested PCB without manually uploading the Gerber files.

## Version

PCB version:

```text
v0.2
```
Status:

```text
Tested and working
```
Recommended for new builds:

```text
Yes
```

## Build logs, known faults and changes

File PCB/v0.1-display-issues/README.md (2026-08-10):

# KOTH Timer PCB v0.1 - Known Display Issues

This folder contains the first manufactured PCB design for the KOTH Timer.

## Status

**Manufactured and partially working, but not recommended for new builds.**

PCB v0.1 has been manufactured and the timer is functional through the web UI, but this revision has known display reliability issues.

## Known Issue

Some TM1637 displays may show:

* Interference
* Flickering
* Incorrect segments
* Unstable or inconsistent output

The main timer logic and web interface can still function, but the display behaviour is not reliable enough for this revision to be recommended as the main PCB build.

## Likely Causes

The display issues may be related to:

* Shared TM1637 clock routing
* Not enough local capacitance near each display header
* Display power noise
* Signal integrity issues on CLK/DIO traces
* Long display wiring or cable effects
* TM1637 modules being sensitive to power or clock noise

## Recommended Use

Use this revision for:

* Reference
* Debugging
* Comparing against newer PCB revisions
* Learning what changed between board versions

Do not order this revision for a new build unless you are comfortable debugging and modifying the board.

## Suggested Bodge Fixes

If you already have a v0.1 PCB, possible fixes to try include:

* Lower the TM1637 display brightness in firmware.
* Add a 100 uF electrolytic capacitor across 5V and GND near each display header.
* Add a 100 nF ceramic capacitor near each display header.
* Add a 100 ohm series resistor on the shared TM1637 CLK line.
* Add 47 to 100 ohm series resistors on the TM1637 DIO lines if needed.
* Keep display wiring as short and tidy as practical.

These fixes may improve reliability but are not guaranteed.

## Version

PCB version:

```text
v0.1
```

Status:

```text
Known display issues
```

Recommended for new builds:

```text
No
```

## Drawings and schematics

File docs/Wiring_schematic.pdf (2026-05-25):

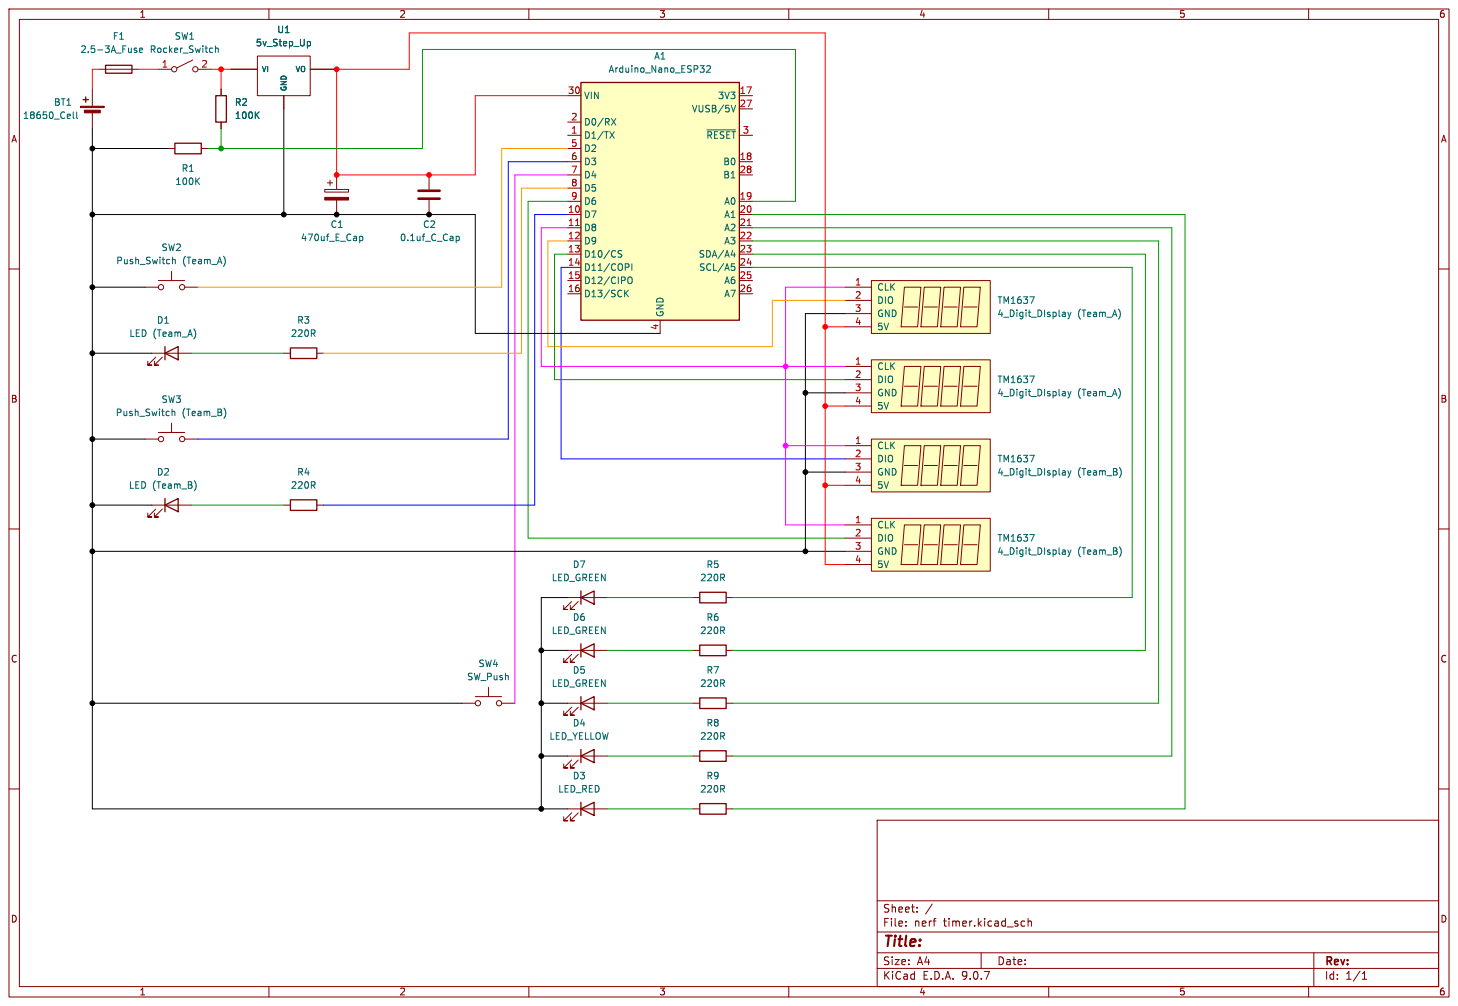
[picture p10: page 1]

Id: 1/1 Title: File: nerf timer.kicad_sch Sheet: / R8

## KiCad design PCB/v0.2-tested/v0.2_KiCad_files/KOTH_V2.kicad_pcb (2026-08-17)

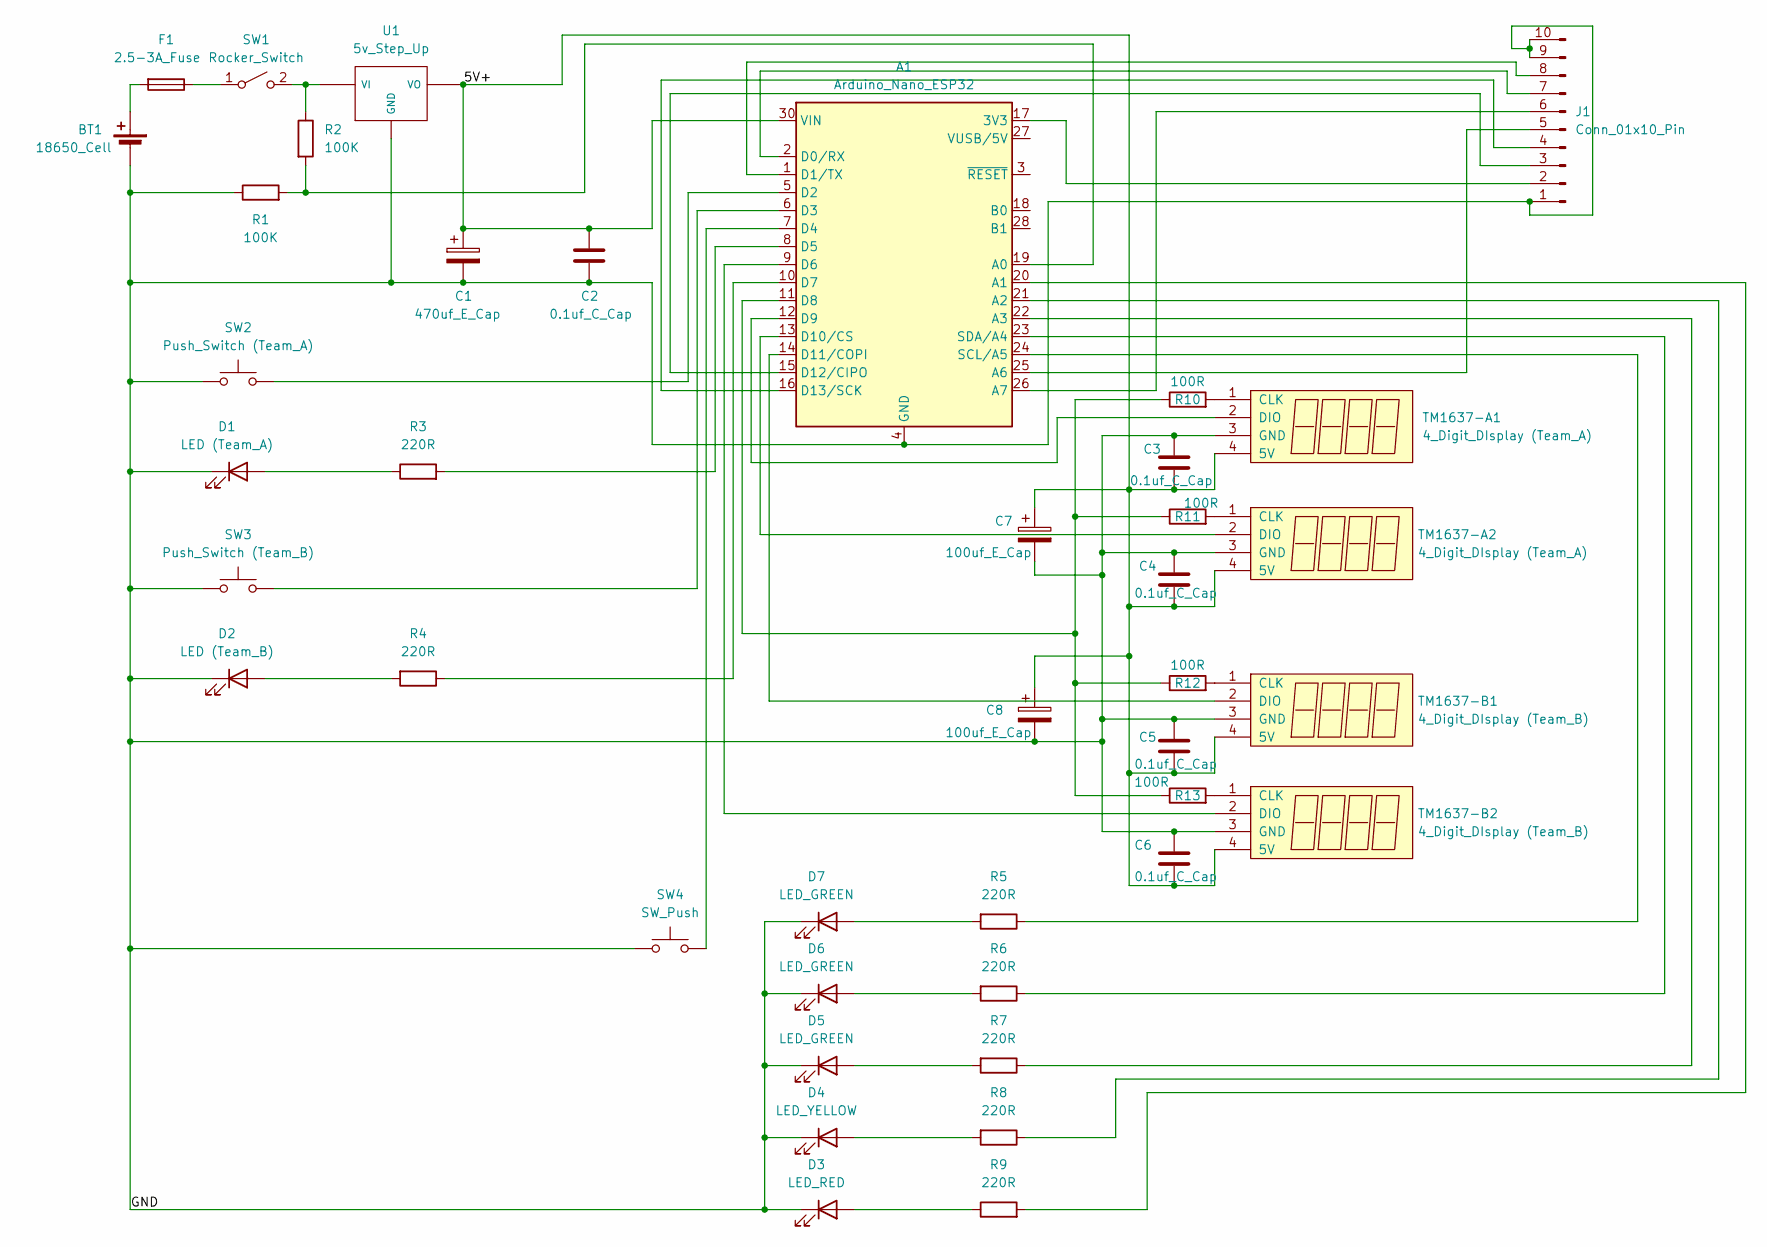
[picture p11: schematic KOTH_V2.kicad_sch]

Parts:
A1: Arduino_Nano_ESP32; Arduino_Nano
BT1: 18650_Cell; TerminalBlock_MaiXu_MX126-5.0-02P_1x02_P5.00mm
C1: 470uf_E_Cap; CP_Radial_D8.0mm_P5.00mm
C2, C3, C4, C5, C6: 0.1uf_C_Cap; C_Disc_D4.3mm_W1.9mm_P5.00mm
C7, C8: 100uf_E_Cap; CP_Radial_D6.3mm_P2.50mm
D1: LED (Team_A); TerminalBlock_MaiXu_MX126-5.0-02P_1x02_P5.00mm
D2: LED (Team_B); TerminalBlock_MaiXu_MX126-5.0-02P_1x02_P5.00mm
D3: LED_RED; R_Axial_DIN0207_L6.3mm_D2.5mm_P7.62mm_Horizontal
D4: LED_YELLOW; R_Axial_DIN0207_L6.3mm_D2.5mm_P7.62mm_Horizontal
D5, D6, D7: LED_GREEN; R_Axial_DIN0207_L6.3mm_D2.5mm_P7.62mm_Horizontal
F1: 2.5-3A_Fuse; Fuseholder_Clip-6.3x32mm_Littelfuse_102_122_Inline_P34.21x7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
J1: Conn_01x10_Pin; PinHeader_2x05_P2.54mm_Vertical
R1, R2: 100K; R_Axial_DIN0309_L9.0mm_D3.2mm_P15.24mm_Horizontal
R3, R4, R5, R6, R7, R8, R9: 220R; R_Axial_DIN0309_L9.0mm_D3.2mm_P15.24mm_Horizontal
R10, R11, R12, R13: 100R; R_Axial_DIN0309_L9.0mm_D3.2mm_P15.24mm_Horizontal
SW1: Rocker_Switch; TerminalBlock_MaiXu_MX126-5.0-02P_1x02_P5.00mm
SW2: Push_Switch (Team_A); TerminalBlock_MaiXu_MX126-5.0-02P_1x02_P5.00mm
SW3: Push_Switch (Team_B); TerminalBlock_MaiXu_MX126-5.0-02P_1x02_P5.00mm
SW4: SW_Push; SW_PUSH-12mm
TM1637-A1, TM1637-A2: 4_Digit_DIsplay (Team_A); TerminalBlock_MaiXu_MX126-5.0-04P_1x04_P5.00mm
TM1637-B1, TM1637-B2: 4_Digit_DIsplay (Team_B); TerminalBlock_MaiXu_MX126-5.0-04P_1x04_P5.00mm
U1: 5v_Step_Up; PinHeader_1x03_P2.54mm_Vertical

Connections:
/5V+: A1.30 (VIN), C1.1, C2.1, C3.2, C4.2, C5.2, C6.2, C7.1, C8.1, TM1637-A1.4 (5V), TM1637-A2.4 (5V), TM1637-B1.4 (5V), TM1637-B2.4 (5V), U1.3 (VO)
/GND: A1.4 (GND), A1.29 (GND), BT1.2 (-), C1.2, C2.2, C3.1, C4.1, C5.1, C6.1, C7.2, C8.2, D1.1 (K), D2.1 (K), D3.1 (K), D4.1 (K), D5.1 (K), D6.1 (K), D7.1 (K), J1.1, J1.9, J1.10, R1.1, SW2.1, SW3.1, SW4.1, TM1637-A1.3 (GND), TM1637-A2.3 (GND), TM1637-B1.3 (GND), TM1637-B2.3 (GND), U1.2 (GND)
unnamed: A1.17 (3V3), J1.2
unnamed: A1.19 (A0), R1.2, R2.2
unnamed: A1.20 (A1), R9.2
unnamed: A1.21 (A2), R8.1
unnamed: A1.22 (A3), R7.1
unnamed: A1.25 (A6), J1.5
unnamed: A1.26 (A7), J1.6
unnamed: A1.2 (D0/RX), J1.7
unnamed: A1.1 (D1/TX), J1.8
unnamed: A1.5 (D2), SW2.2
unnamed: A1.6 (D3), SW3.2
unnamed: A1.7 (D4), SW4.2
unnamed: A1.8 (D5), R3.2
unnamed: A1.9 (D6), TM1637-B2.2 (DIO)
unnamed: A1.10 (D7), R4.1
unnamed: A1.11 (D8), R10.1, R11.1, R12.1, R13.1
unnamed: A1.12 (D9), TM1637-A1.2 (DIO)
unnamed: A1.13 (D10/CS), TM1637-A2.2 (DIO)
unnamed: A1.14 (D11/COPI), TM1637-B1.2 (DIO)
unnamed: A1.15 (D12/CIPO), J1.3
unnamed: A1.16 (D13/SCK), J1.4
unnamed: A1.24 (SCL/A5), R5.1
unnamed: A1.23 (SDA/A4), R6.1
unnamed: BT1.1 (+), F1.2
unnamed: D1.2 (A), R3.1
unnamed: D2.2 (A), R4.2
unnamed: D3.2 (A), R9.1
unnamed: D4.2 (A), R8.2
unnamed: D5.2 (A), R7.2
unnamed: D6.2 (A), R6.2
unnamed: D7.2 (A), R5.2
unnamed: F1.1, SW1.1 (A)
unnamed: R2.1, SW1.2 (B), U1.1 (VI)
unnamed: R10.2, TM1637-A1.1 (CLK)
unnamed: R11.2, TM1637-A2.1 (CLK)
unnamed: R12.2, TM1637-B1.1 (CLK)
unnamed: R13.2, TM1637-B2.1 (CLK)

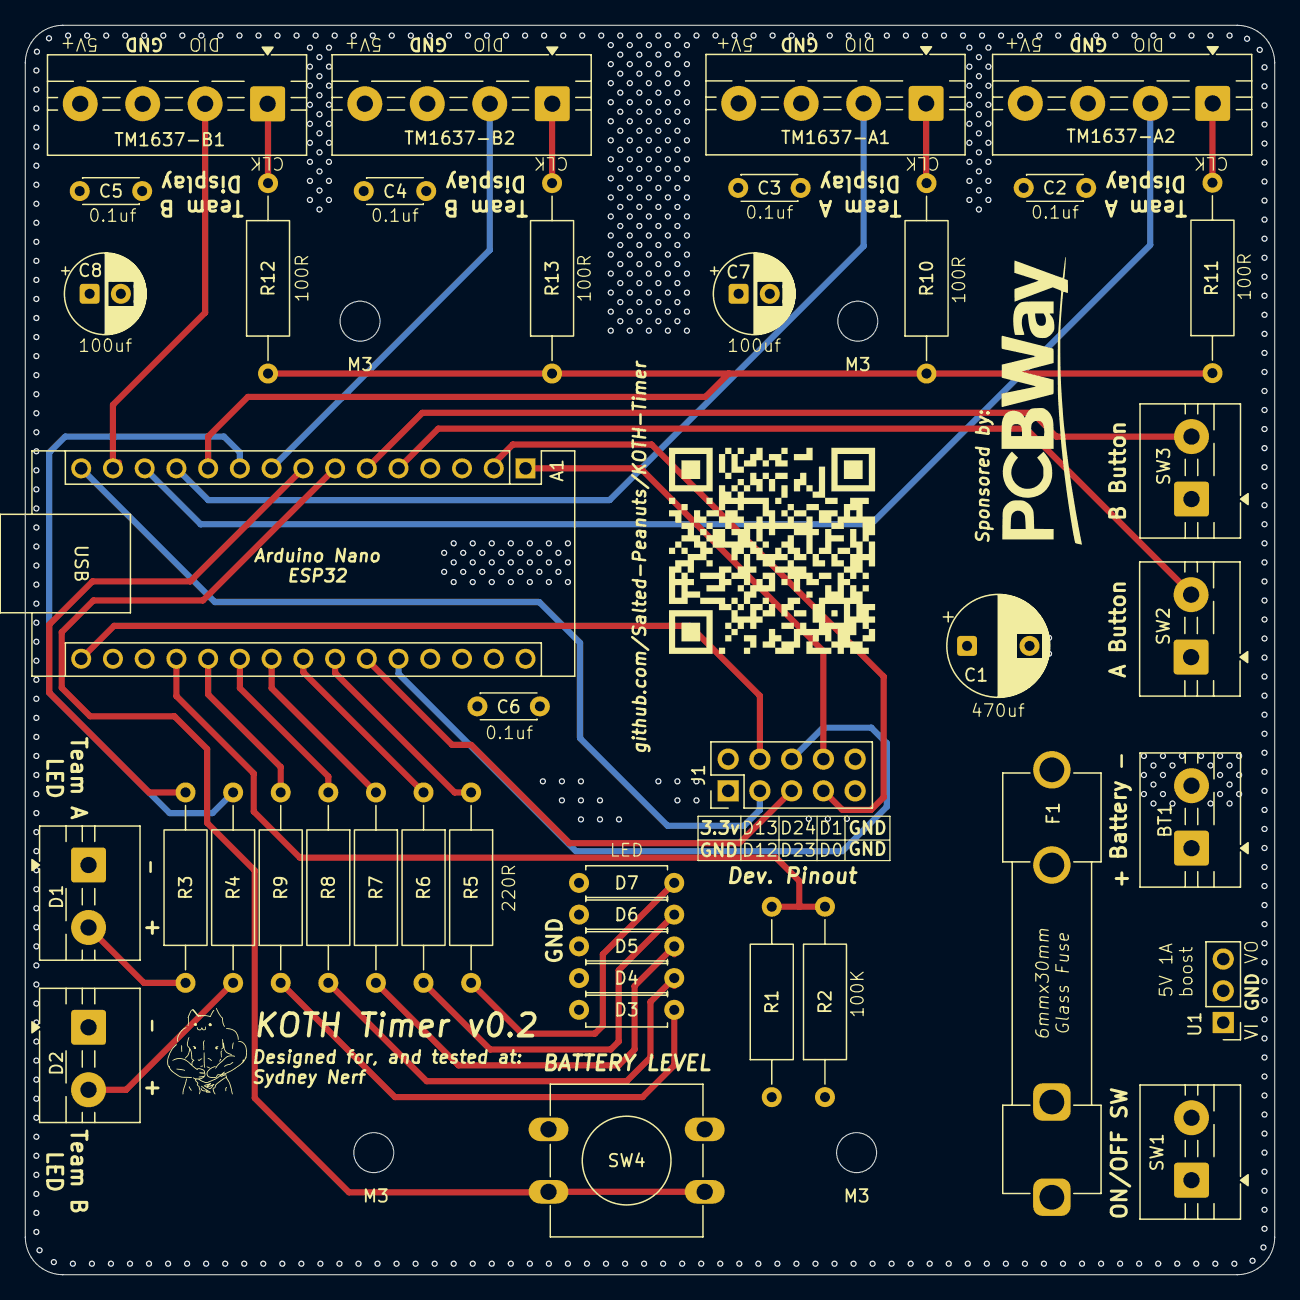
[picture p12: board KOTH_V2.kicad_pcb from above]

Board: 4 copper layers, 100.0 x 100.0 mm, 47 parts (1 on the bottom side), 39 nets.

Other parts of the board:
M3, M3#2, M3#3, M3#4: MountingHole_3.2mm_M3
QR*****: QRKOTH-Timer
QR*****#2: QRKOTH-Timer

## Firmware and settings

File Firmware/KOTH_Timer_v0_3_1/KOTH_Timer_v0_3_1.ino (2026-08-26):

// ---- IMPORTANT: define CaptureState BEFORE Arduino auto-prototypes ----
#include <stdint.h>
enum CaptureState : uint8_t { ST_READY, ST_IDLE, ST_A, ST_B, ST_CONTESTED, ST_DONE };
// ----------------------------------------------------------------------

#include <WiFi.h>
#include <WebServer.h>
#include <WebSocketsServer.h>
#include <Preferences.h>
#include <TM1637Display.h>
#include <DNSServer.h>

/*
  Arduino Nano ESP32 (NORA-W106) - King of the Hill Timer
  FULL CODE (current spec)

  Game rules:
  - Only counts down while EXACTLY ONE team button is held
  - Both held => contested (no score)
  - None held => no score
  - Match ends when either team timer reaches 0

  Hardware:
  - 4x TM1637 displays (2 per team)
  - 2x arcade buttons + their LEDs (GPIO driven)
  - Battery ADC divider + bargraph indicator with separate "show battery" button
  - Bargraph wiring: common GND, each segment -> resistor -> GPIO (GPIO HIGH = ON)

  Battery smoothing:
  - Uses oversampling + EMA low-pass filter for stable voltage readout.
*/

// ===== Wi-Fi AP =====
static const char* AP_SSID = "KOTH-Timer";
static const char* AP_PASS = ""; 
// Leave blank for open Wi-Fi.
// Optional: use "kothtimer" if you want a password later.
// Password must be at least 8 characters if used.

static const uint8_t AP_CHANNEL = 1;
static const uint8_t AP_MAX_CLIENTS = 3;
static const bool AP_HIDDEN = false;

static IPAddress AP_IP(10, 10, 10, 1);
static IPAddress AP_GATEWAY(10, 10, 10, 1);
static IPAddress AP_SUBNET(255, 255, 255, 0);

static const byte DNS_PORT = 53;
static DNSServer dnsServer;

//// ===== Pins (Arduino Nano ESP32 labels) =====
// Buttons (to GND, INPUT_PULLUP)
static const int PIN_BTN_A   = D2;
static const int PIN_BTN_B   = D3;
static const int PIN_BTN_BAT = D4;

// Arcade button LEDs (GPIO -> resistor -> LED -> GND). HIGH = ON
static const int PIN_LED_A   = D5;
static const int PIN_LED_B   = D7;

// TM1637 (VCC -> VIN, GND -> GND)
static const int PIN_TM_CLK  = D8;
static const int PIN_TM_A1   = D9;
static const int PIN_TM_A2   = D10;
static const int PIN_TM_B1   = D11;
static const int PIN_TM_B2   = D6;   // moved off D12 (unreliable)

// Battery ADC divider midpoint
static const int PIN_BATT_ADC = A0;

// 5-bar battery indicator (common GND; GPIO HIGH = ON)
static const int PIN_BAR_RED    = A1;
static const int PIN_BAR_YELLOW = A2;
static const int PIN_BAR_G1     = A3;
static const int PIN_BAR_G2     = A4;
static const int PIN_BAR_G3     = A5;

//// ===== Battery divider (set to your actual divider values) =====
static const float R1 = 100000.0f;
static const float R2 = 100000.0f;

//// ===== Battery calibration knobs =====
// Tune with multimeter.
// Example: multimeter 4.12V, UI shows 3.95V => ADC_GAIN = 4.12/3.95 = 1.043
static const float ADC_GAIN   = 0.634f;
static const float ADC_OFFSET = 0.000f; // volts

//// ===== Battery smoothing knobs =====
// EMA_ALPHA: 0.05 = very smooth/slow, 0.20 = faster response
static const float EMA_ALPHA = 0.12f;
// Update period for the EMA input sample
static const uint32_t BATT_UPDATE_MS = 1000;
// Oversampling per raw read
static const int BATT_SAMPLES = 8;

//// ===== Debounce =====
struct DebouncedButton {
  int pin;
  bool stable;      // HIGH not pressed, LOW pressed
  bool lastReading;
  uint32_t lastChangeMs;
};
static const uint32_t DEBOUNCE_MS = 25;

static DebouncedButton btnA  {PIN_BTN_A,   true, true, 0};
static DebouncedButton btnB  {PIN_BTN_B,   true, true, 0};
static DebouncedButton btnBt {PIN_BTN_BAT, true, true, 0};

static inline void readDebounced(DebouncedButton &b) {
  bool r = digitalRead(b.pin);
  if (r != b.lastReading) {
    b.lastReading = r;
    b.lastChangeMs = millis();
  }
  if (millis() - b.lastChangeMs > DEBOUNCE_MS) {
    b.stable = r;
  }
}
static inline bool isPressed(const DebouncedButton &b) { return b.stable == LOW; }

//// ===== State / Config =====
static Preferences prefs;

static uint32_t durationSec = 5 * 60;
static int32_t remainingA = 5 * 60;
static int32_t remainingB = 5 * 60;

static bool started = false;
static bool paused  = false;

static String colorA = "#ff3333";
static String colorB = "#3333ff";

static CaptureState captureState = ST_READY;

static uint32_t lastTickMs = 0;
static uint32_t accumMs = 0;

//// ===== Identify mode =====
static bool identifyMode = false;
static uint32_t identifyUntilMs = 0;

//// ===== Battery / bargraph =====
static float battVolts = 0.0f;     // SMOOTHED
static float battVoltsRaw = 0.0f;  // instantaneous (for debugging if you want)
static int battPct = 0;

static bool barActive = false;
static uint32_t barOffAtMs = 0;
static const uint32_t BAR_SHOW_MS = 5000;

//// ===== Displays =====
static TM1637Display dispA1(PIN_TM_CLK, PIN_TM_A1);
static TM1637Display dispA2(PIN_TM_CLK, PIN_TM_A2);
static TM1637Display dispB1(PIN_TM_CLK, PIN_TM_B1);
static TM1637Display dispB2(PIN_TM_CLK, PIN_TM_B2);

//// ===== Web =====
static WebServer server(80);
static WebSocketsServer ws(81);
static uint32_t lastBroadcastMs = 0;

//// ===== Helpers =====
static String formatMMSS(int32_t s) {
  if (s < 0) s = 0;
  int32_t m = s / 60;
  int32_t r = s % 60;
  char buf[8];
  snprintf(buf, sizeof(buf), "%02ld:%02ld", (long)m, (long)r);
  return String(buf);
}
static uint16_t encodeMMSS(int32_t s) {
  if (s < 0) s = 0;
  int mm = (int)(s / 60);
  int ss = (int)(s % 60);
  return (uint16_t)(mm * 100 + ss);
}
static void resetTimers() {
  remainingA = (int32_t)durationSec;
  remainingB = (int32_t)durationSec;
}

static const int32_t MAX_REMAINING_SEC = (99 * 60) + 59; // TM1637 MM:SS practical max

static int32_t clampRemainingTime(int32_t seconds) {
  if (seconds < 0) return 0;
  if (seconds > MAX_REMAINING_SEC) return MAX_REMAINING_SEC;
  return seconds;
}

static void adjustTeamTime(const String &team, int32_t deltaSec) {
  if (team == "A") {
    remainingA = clampRemainingTime(remainingA + deltaSec);
  } else if (team == "B") {
    remainingB = clampRemainingTime(remainingB + deltaSec);
  }

  // Prevent an immediate extra second being removed straight after adjustment.
  accumMs = 0;
  lastTickMs = millis();

  updateDisplays();
}

static void loadConfig() {
  prefs.begin("koth", true);
  durationSec = prefs.getUInt("dur", 5 * 60);
  colorA = prefs.getString("colA", "#ff3333");
  colorB = prefs.getString("colB", "#3333ff");
  prefs.end();

  if (durationSec < 60) durationSec = 60;
  if (durationSec > 60 * 60) durationSec = 60 * 60;
}
static void saveConfig() {
  prefs.begin("koth", false);
  prefs.putUInt("dur", durationSec);
  prefs.putString("colA", colorA);
  prefs.putString("colB", colorB);
  prefs.end();
}

// Leading zero suppression on TM1637 when < 10 minutes (600 seconds)
static void showTimeOn(TM1637Display &d, int32_t seconds, uint8_t colonMask) {
  uint16_t v = encodeMMSS(seconds);
  bool leadingZero = (seconds >= 600); // show leading 0 only for 10:00 and above
  d.showNumberDecEx(v, colonMask, leadingZero);
}
static void updateDisplays() {
  const uint8_t colonMask = 0b01000000;
  showTimeOn(dispA1, remainingA, colonMask);
  showTimeOn(dispA2, remainingA, colonMask);
  showTimeOn(dispB1, remainingB, colonMask);
  showTimeOn(dispB2, remainingB, colonMask);
}

// Winner string used by UI
static String winnerString() {
  // Match ends when either team reaches 0
  if (remainingA <= 0 && remainingB <= 0) return "DRAW";
  if (remainingA <= 0) return "TEAM_A";
  if (remainingB <= 0) return "TEAM_B";
  return "";
}

// Battery conversion
static float readBattVoltsInstant() {
  uint32_t sum = 0;
  for (int i = 0; i < BATT_SAMPLES; i++) {
    sum += analogRead(PIN_BATT_ADC);
    delay(1);
  }
  float raw = (float)sum / (float)BATT_SAMPLES;

  float v_adc  = (raw / 4095.0f) * 3.3f;
  float v_batt = v_adc * ((R1 + R2) / R2);

  // Calibration knobs
  v_batt = (v_batt * ADC_GAIN) + ADC_OFFSET;

  return v_batt;
}

static int voltsToPct(float v) {
  if (v >= 4.20f) return 100;
  if (v <= 3.30f) return 0;
  if (v >= 4.00f) return (int)(80 + (v - 4.00f) * (20.0f / 0.20f));
  if (v >= 3.85f) return (int)(55 + (v - 3.85f) * (25.0f / 0.15f));
  if (v >= 3.70f) return (int)(30 + (v - 3.70f) * (25.0f / 0.15f));
  if (v >= 3.50f) return (int)(10 + (v - 3.50f) * (20.0f / 0.20f));
  return (int)((v - 3.30f) * (10.0f / 0.20f));
}
static int voltsToBars(float v) {
  if (v >= 4.10f) return 5;
  if (v >= 3.95f) return 4;
  if (v >= 3.80f) return 3;
  if (v >= 3.65f) return 2;
  if (v >= 3.45f) return 1;
  return 0;
}

// Bargraph outputs: HIGH=ON, LOW=OFF (your wiring)
static void barAllOff() {
  digitalWrite(PIN_BAR_RED, LOW);
  digitalWrite(PIN_BAR_YELLOW, LOW);
  digitalWrite(PIN_BAR_G1, LOW);
  digitalWrite(PIN_BAR_G2, LOW);
  digitalWrite(PIN_BAR_G3, LOW);
}
static void barShowBars(int bars) {
  digitalWrite(PIN_BAR_RED,    (bars >= 1) ? HIGH : LOW);
  digitalWrite(PIN_BAR_YELLOW, (bars >= 2) ? HIGH : LOW);
  digitalWrite(PIN_BAR_G1,     (bars >= 3) ? HIGH : LOW);
  digitalWrite(PIN_BAR_G2,     (bars >= 4) ? HIGH : LOW);
  digitalWrite(PIN_BAR_G3,     (bars >= 5) ? HIGH : LOW);
}
static void triggerBarShow() {
  barActive = true;
  barOffAtMs = millis() + BAR_SHOW_MS;
}

static void evaluateCaptureState(bool aHeld, bool bHeld) {
  if (remainingA <= 0 || remainingB <= 0) { captureState = ST_DONE; return; }
  if (!started) { captureState = ST_READY; return; }
  if (paused) { captureState = ST_IDLE; return; }

  if (aHeld && !bHeld) captureState = ST_A;
  else if (bHeld && !aHeld) captureState = ST_B;
  else if (aHeld && bHeld) captureState = ST_CONTESTED;
  else captureState = ST_IDLE;
}

static const char* stateToStr(CaptureState s) {
  switch (s) {
    case ST_READY:     return "READY";
    case ST_IDLE:      return "IDLE";
    case ST_A:         return "TEAM_A";
    case ST_B:         return "TEAM_B";
    case ST_CONTESTED: return "CONTESTED";
    case ST_DONE:      return "DONE";
    default:           return "IDLE";
  }
}

static String makeStateJson() {
  String win = winnerString();

  String json = "{";
  json += "\"a\":\"" + formatMMSS(remainingA) + "\",";
  json += "\"b\":\"" + formatMMSS(remainingB) + "\",";
  json += "\"status\":\"" + String(stateToStr(captureState)) + "\",";
  json += "\"started\":" + String(started ? "true" : "false") + ",";
  json += "\"paused\":" + String(paused ? "true" : "false") + ",";
  json += "\"dur\":" + String(durationSec) + ",";
  json += "\"colA\":\"" + colorA + "\",";
  json += "\"colB\":\"" + colorB + "\",";
  json += "\"bv\":" + String(battVolts, 2) + ",";
  json += "\"bp\":" + String(battPct) + ",";
  json += "\"identify\":" + String(identifyMode ? "true" : "false") + ",";
  json += "\"winner\":\"" + win + "\"";
  json += "}";
  return json;
}

static void broadcastState() {
  String payload = makeStateJson(); // lvalue needed by WebSockets 2.7.2
  ws.broadcastTXT(payload);
}

//// ===== UI (no Wi-Fi strength; reset lock; winner shown) =====
static const char INDEX_HTML[] PROGMEM = R"HTML(
<!doctype html>
<html lang="en">
<head>
<meta charset="utf-8">
<meta name="viewport" content="width=device-width,initial-scale=1,viewport-fit=cover">
<meta name="theme-color" content="#101216">
<title>KOTH Timer</title>
<style>
:root{
  --bg:#101216;
  --panel:#1a1f28;
  --panel2:#232a36;
  --line:#343c4b;
  --text:#f5f7fb;
  --muted:#aab3c2;
  --a:#ff3333;
  --b:#3333ff;
  --aText:#fff;
  --bText:#fff;
  --blue:#4aa3ff;
  --green:#35d07f;
  --yellow:#f3c84b;
  --red:#ff6464;
}
*{box-sizing:border-box;-webkit-tap-highlight-color:transparent}
html,body{margin:0;min-height:100%;background:var(--bg);color:var(--text);font-family:system-ui,-apple-system,BlinkMacSystemFont,"Segoe UI",sans-serif}
body{padding:env(safe-area-inset-top) 0 env(safe-area-inset-bottom)}
.app{width:100%;max-width:520px;margin:0 auto;padding:12px 12px 24px}
.top{display:flex;align-items:center;justify-content:space-between;gap:10px;margin-bottom:10px}
h1{font-size:1.15rem;margin:0;font-weight:900;letter-spacing:.02em}
.pill{display:inline-flex;align-items:center;justify-content:center;gap:6px;border:1px solid var(--line);background:var(--panel);color:var(--muted);border-radius:999px;padding:7px 10px;font-size:.78rem;white-space:nowrap}
.pill.good{color:#b8ffd5;border-color:#23653f}
.pill.bad{color:#ffd0d0;border-color:#713434}
.statusBox{border:1px solid var(--line);background:linear-gradient(180deg,var(--panel2),var(--panel));border-radius:18px;padding:14px;margin-bottom:10px;text-align:center}
.statusMain{font-size:1.35rem;font-weight:950;line-height:1.1}
.statusSub{margin-top:5px;color:var(--muted);font-size:.9rem}
.teams{display:grid;gap:10px}
.teamCard{position:relative;overflow:hidden;border:1px solid var(--line);background:var(--panel);border-radius:20px;padding:12px 12px 14px}
.teamCard::before{content:"";position:absolute;left:0;top:0;bottom:0;width:8px;background:var(--team)}
.teamHead{display:flex;align-items:center;justify-content:space-between;margin-left:8px;gap:10px}
.teamName{font-size:1rem;font-weight:900}
.teamHint{font-size:.78rem;color:var(--muted)}
.time{font-variant-numeric:tabular-nums;text-align:center;font-size:4.15rem;line-height:1;font-weight:950;letter-spacing:-.055em;padding:4px 0 0}
.teamCard.active{box-shadow:0 0 0 2px var(--team) inset}
.teamCard.done{opacity:.72}
.grid2{display:grid;grid-template-columns:1fr 1fr;gap:10px}
.grid3{display:grid;grid-template-columns:1fr 1fr 1fr;gap:10px}
.section{border:1px solid var(--line);background:var(--panel);border-radius:20px;padding:12px;margin-top:10px}
.sectionTitle{font-size:1rem;font-weight:900;margin:0 0 10px}
button{width:100%;min-height:54px;border:0;border-radius:15px;background:#303848;color:var(--text);font-size:1rem;font-weight:900;padding:12px 10px;cursor:pointer}
button:active{transform:scale(.98);filter:brightness(1.13)}
button.primary{background:var(--blue);color:#061321}
button.good{background:var(--green);color:#04170c}
button.warn{background:var(--yellow);color:#1f1700}
button.bad{background:var(--red);color:#250000}
button.teamAdjustA{background:var(--a);color:var(--aText)}
button.teamAdjustB{background:var(--b);color:var(--bText)}
button.minus{filter:saturate(.75) brightness(.82)}
button.minus:active{filter:saturate(.75) brightness(1)}
button:disabled{opacity:.35;cursor:not-allowed;transform:none;filter:none}
label{display:block;color:var(--muted);font-size:.82rem;font-weight:750}
input[type=number]{width:100%;min-height:48px;margin-top:6px;border-radius:13px;border:1px solid var(--line);background:#10141b;color:var(--text);font-size:1.1rem;font-weight:850;padding:8px 10px}
input[type=color]{width:100%;height:48px;margin-top:6px;border:1px solid var(--line);border-radius:13px;background:#10141b;padding:4px}
.help{color:var(--muted);font-size:.82rem;line-height:1.35;margin-top:8px}
details{border:1px solid var(--line);background:var(--panel);border-radius:20px;padding:0;margin-top:10px;overflow:hidden}
summary{list-style:none;cursor:pointer;padding:14px 12px;font-size:1rem;font-weight:900}
summary::-webkit-details-marker{display:none}
.detailsInner{padding:0 12px 12px}
.sep{height:10px}
.miniStats{display:grid;grid-template-columns:1fr 1fr;gap:8px;margin-top:10px}
.stat{border:1px solid var(--line);background:#121720;border-radius:14px;padding:9px;text-align:center}
.statLabel{color:var(--muted);font-size:.72rem}
.statValue{font-size:.95rem;font-weight:900;margin-top:2px}
@media (max-width:380px){
  .app{padding-left:9px;padding-right:9px}
  .time{font-size:3.45rem}
  button{font-size:.92rem;min-height:50px}
  .statusMain{font-size:1.15rem}
}
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
void loop(){
  dnsServer.processNextRequest();
  server.handleClient();
  ws.loop();

  const uint32_t now = millis();

  // ---- Smooth battery update ----
  static uint32_t lastBattMs = 0;
  if(now - lastBattMs >= BATT_UPDATE_MS){
    battVoltsRaw = readBattVoltsInstant();
    battVolts = battVolts + EMA_ALPHA * (battVoltsRaw - battVolts); // EMA smoothing
    battPct = voltsToPct(battVolts);
    lastBattMs = now;
  }

  // ---- Battery bar button ----
  readDebounced(btnBt);
  static bool lastBat = false;
  bool batNow = isPressed(btnBt);
  if(batNow && !lastBat) triggerBarShow();
  lastBat = batNow;

  if(barActive){
    barShowBars(voltsToBars(battVolts));
    if((int32_t)(now - barOffAtMs) >= 0){
      barActive = false;
      barAllOff();
    }
  } else {
    barAllOff();
  }

  // ---- Identify mode (stopped only): flash displays + LEDs ----
  if(identifyMode){
    if((int32_t)(now - identifyUntilMs) >= 0){
      identifyMode = false;
      dispA1.clear(); dispA2.clear(); dispB1.clear(); dispB2.clear();
      digitalWrite(PIN_LED_A, LOW);
      digitalWrite(PIN_LED_B, LOW);
    } else {
      bool blink = (now / 400) % 2;

      if(blink){
        dispA1.showNumberDec(1111, false);
        dispA2.showNumberDec(1111, false);
        dispB1.showNumberDec(2222, false);
        dispB2.showNumberDec(2222, false);
        digitalWrite(PIN_LED_A, HIGH);
        digitalWrite(PIN_LED_B, HIGH);
      } else {
        dispA1.clear(); dispA2.clear(); dispB1.clear(); dispB2.clear();
        digitalWrite(PIN_LED_A, LOW);
        digitalWrite(PIN_LED_B, LOW);
      }

      // keep UI live
      if(now - lastBroadcastMs >= 500){
        broadcastState();
        lastBroadcastMs = now;
      }
      return; // skip normal game logic during identify
    }
  }

  // ---- Read team buttons ----
  readDebounced(btnA);
  readDebounced(btnB);

  bool aHeld = isPressed(btnA);
  bool bHeld = isPressed(btnB);

  // ---- Evaluate capture state ----
  evaluateCaptureState(aHeld, bHeld);

  // ---- Arcade button LED logic ----
  if(!started){
    digitalWrite(PIN_LED_A, LOW);
    digitalWrite(PIN_LED_B, LOW);
  } else if(captureState == ST_A){
    digitalWrite(PIN_LED_A, HIGH);
    digitalWrite(PIN_LED_B, LOW);
  } else if(captureState == ST_B){
    digitalWrite(PIN_LED_A, LOW);
    digitalWrite(PIN_LED_B, HIGH);
  } else if(captureState == ST_CONTESTED){
    digitalWrite(PIN_LED_A, HIGH);
    digitalWrite(PIN_LED_B, HIGH);
  } else {
    digitalWrite(PIN_LED_A, LOW);
    digitalWrite(PIN_LED_B, LOW);
  }

  // ---- Countdown tick ----
  uint32_t elapsedMs = now - lastTickMs;
  lastTickMs = now;

  if(started && !paused && (captureState == ST_A || captureState == ST_B)){
    accumMs += elapsedMs;
    while(accumMs >= 1000){
      accumMs -= 1000;
      if(captureState == ST_A){
        if(remainingA > 0) remainingA--;
      } else {
        if(remainingB > 0) remainingB--;
      }
    }
  } else {
    accumMs = 0;
  }

  // ---- Update display ----
  static uint32_t lastDispMs = 0;
  if(now - lastDispMs >= 100){
    updateDisplays();
    lastDispMs = now;
  }

  // ---- Broadcast to UI ----
  if(now - lastBroadcastMs >= 500){
    broadcastState();
    lastBroadcastMs = now;
  }

  delay(1);
}

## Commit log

2026-05-25 Rename nerf timer.pdf to KOTH_schematic.pdf
2026-05-25 Rename nerf timer BOM.xlsx to BOM.xlsx
    [BOM.xlsx]
2026-07-02 Create KiCad_files
2026-07-12 Add files via upload
    PCB reference images uploaded.
2026-08-17 Update PCB status
    [nerf timer.kicad_pcb, nerf timer.kicad_sch]
2026-08-18 Update README.md
    Device rename
2026-08-18 Update README.md
    Update device name
2026-08-18 Add files via upload
    v0.2 PCB reference images
2026-08-26 PCB update
    [KOTH_V2.kicad_pcb, KOTH_V2.kicad_sch]
2026-08-26 Create KOTH_Timer_v0_3_1.ino
    Minor firmware update to better support the release of working PCB
2026-11-11 KOTH Timer v0.4.0
    Release firmware v0.4.0 with updated battery monitoring, optional buzzer support, physical start controls, low-battery recovery, BOM corrections and refreshed documentation.
2026-11-11 Add reference build buzzer to BOM
2026-11-11 Add tested Keyestudio buzzer to BOM
